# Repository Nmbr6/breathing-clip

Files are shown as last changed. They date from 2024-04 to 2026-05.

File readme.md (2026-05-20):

# Real-time Wearable Respiratory Monitoring System

This project develops a proof-of-concept real-time respiratory monitoring system designed to be non-intrusive, capable of capturing recognizable breathing signals, and transmitting the data over UDP. It is aimed at enabling respiratory based interactions, ensuring simple mounting and adaptability to different positions.

## Referencing

If you use the code or 3D print files included here for your research, please kindly cite the relevant papers in your publications. This support is critical for the continued development and maintenance of the software, as well as recognition of the effort by the authors. Relevant publications include:
* BreathClip: A Wearable Respiration Sensor for Interaction Design \[[link](https://doi.org/10.18420/muc2025-mci-demo-306)]
* Enriched Embodiment Environments for Healthcare Spaces: Exploration through the Design of a Cancer Treatment Facility \[[link](https://doi.org/10.1145/3706599.3719733)]
  
### Other breathing projects:
* Breathing based immersive interactions for enhanced agency and body awareness: a claustrophobia motivated study \[[link](https://dl.acm.org/doi/full/10.1145/3544549.3585897)]
* Enhancing interoceptive sensibility through exteroceptive–interoceptive sensory substitution \[[link](https://doi.org/10.1038/s41598-024-63231-4)]

## Platform

- **Device**: [M5 StickC Plus2](https://docs.m5stack.com/en/core/M5StickC%20PLUS2), built on the ESP32-PICO-V3-02 SoC.
- **IMU**: MPU6886 6-axis IMU for motion tracking.
- **Power**: Equipped with a 200mAh battery.
- **WiFi**: Onboard 2.4GHz antenna utilizing the ESP32 WiFi stack for data transmission.

## Wi-Fi Transmitter Details

- **Wi-Fi Protocol**: 2.4GHz (802.11b/g/n).
- **UDP Port**: 1234 for data streaming.
- **Output Data Rate**: ~500Hz, corresponding to every 2ms.
- **IP Address**: Assigned dynamically.
- **Device Identifier**: Incorporates a "patient_id" as an unsigned 4-digit integer.
- **Packet Type**: 20-byte string format "patient_id,elapsedTime,ac_sig", where:
  - `patient_id` is an unsigned 4-digit integer.
  - `elapsedTime` is an unsigned 32-bit integer, indicating time in milliseconds since power-on, with a maximum stored value representing 49.7 days.
  - `ac_sig` is a signed 16-bit integer showing the accelerometer signal in G-force (units of 0.1mG).

## User Input/Output

- **Front Button**: Toggles the device's LED on or off.
- **Side Button**: Pauses or resumes the UDP stream, effectively toggling the stream state.
- **PWR Button**: Powers the device on (long press ~2 seconds) or off (long press ~6 seconds).

## First-time Setup

**Arduino Libraries**
- M5StickCPlus2 (1.0.1)
- M5Family (0.1.3)
- M5Stack (0.4.6)
- M5Unified (0.1.14)

Accept all dependencies when installing or updating.

**Arduino Board Manager**
- M5Stack (v2.0.7)

**Drivers**
- Install CH9102 UART driver [here](https://docs.m5stack.com/en/core/M5StickC%20PLUS2) ('Driver Installation').
Choose appropriate installer for Windows or MacOS.

**Header Files**
- In your Arduino libraries folder, navigate to <...\Arduino\libraries\M5Unified\src\utility\imu>
Open MPU6886_Class.cpp, then edit Line 61 to match this: setAccelFsr(Ascale::AFS_2G);
This adjusts the full-scale range of IMU data to its highest resolution (+/- 2G)
- To run the code effectively, modify the IMU header file within the M5StickC library to set the resolution to its maximum by editing the `MPU6886.h` file: change line 66 to `Ascale Acscale = AFS_2G;`.

## Before Sketch Upload

- Edit Patient ID: set unique alphanumeric ID per unit (Line 24)
- Edit WiFi credentials (Lines 27-28)

## Mounting

We suggest two methods for mounting - magnetic tape, or a 3D printed clip which can be found in the Git.
### Magnetic tape
 We used Magnetic tape with adhesive backing, with one segment attached to the device, and one simply placed inside the garment. 
 
### 3D printed clip
The STL for printing the clip can be found [here](https://github.com/Nmbr6/breathing-clip/blob/main/Sensor%20Clip.STL) in the GIT. We suggest printing it vertically, oriented so that the clip opening is facing up.

<p align="center">
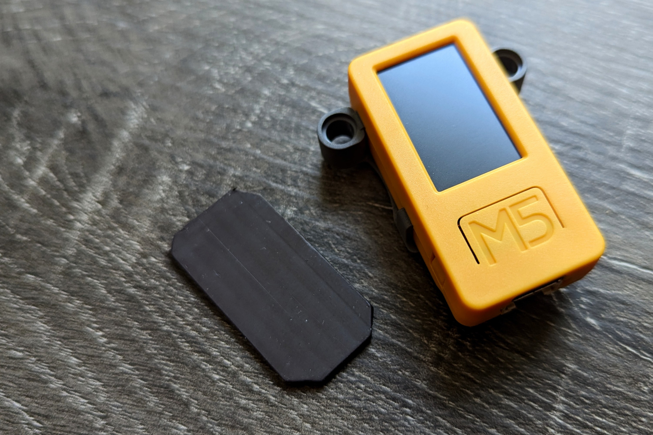
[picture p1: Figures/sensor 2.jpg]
    
</p>

## Placement

For optimal signal capture, the device should be placed over clothing on the clavicle, approximately midway between the sternoclavicular and acromioclavicular joints. The M5 StickC Plus2 should be perpendicular to the clavicle, ensuring accurate signal detection.

<p align="center">
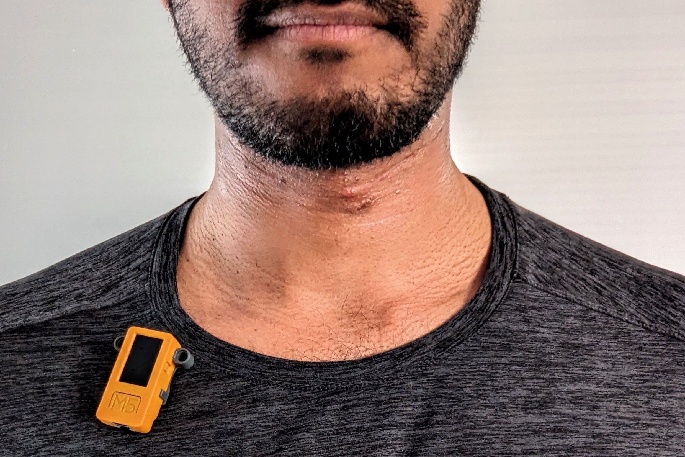
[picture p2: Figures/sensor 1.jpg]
  
</p>

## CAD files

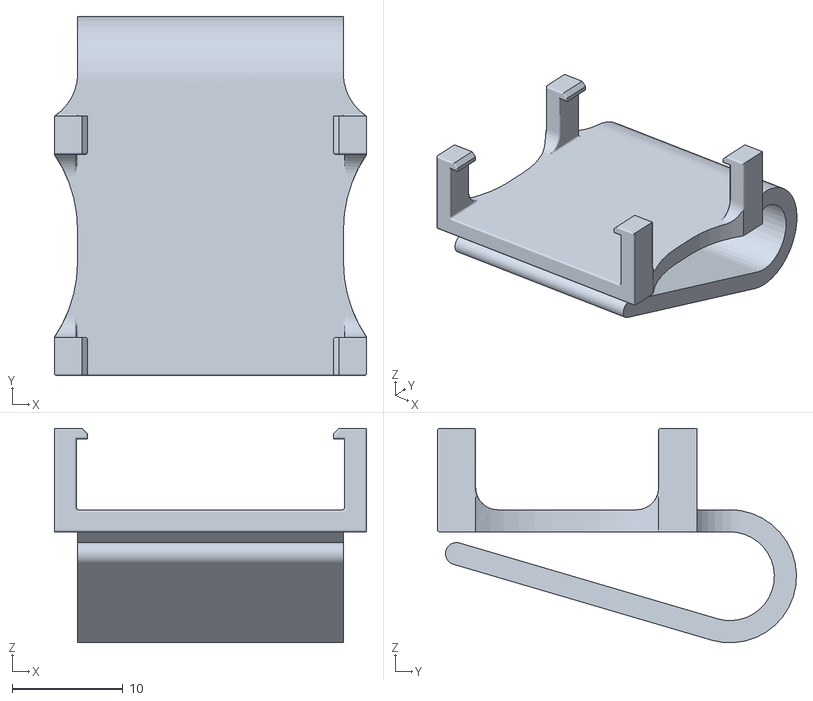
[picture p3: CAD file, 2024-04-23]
Sensor Clip.STL
28.2 x 32.4 x 19.3

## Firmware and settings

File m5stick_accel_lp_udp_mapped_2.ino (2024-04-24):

/*  Proof-of-concept code for Breathing Clip sensor
 *  Shreyas Renganathan, 4/14/2024
 *  This sketch is written for the M5StickCPlus2.
 *  This sketch continuously reads the onboard IMU (MPU6886), filters the data, and streams it over a WiFi network via UDP broadcast
 *  Output data rate is ~500Hz in empirical testing, but will vary based on network speed/bandwidth.
 *  Signal processing algorithm maps the breathing signal output b(t) to -1000<b(t)<1000. The intent is that this can be divided by 1000.0 on the receiver side to obtain a float value -1.0<B(t)<1.0.
 *  This algorithm works by variously filtering the signal to remove noise, then clipping it to a preset range that is known to be narrower than the observed range.
 *  This clipped sinewave is then lowpass filtered again to reconstruct a sinusoidal signal. The reconstructed signal is therefore effectively mapped to the preset range.
 *  NOTE: Follow all setup instructions in Readme.md first
 */
#include "M5StickCPlus2.h"
#include "WiFi.h"
#include "AsyncUDP.h"

/* INITIALIZATIONS */
const int LED_PIN=19;
const bool OFF=HIGH;
const bool ON=LOW;
bool STREAM_EN = false;
bool LED_STATE = ON;
int streamPrint = false;

/* Enter patient ID# here */
const int patient_id = 2308;

/* Set WiFi credentials here */
const char* ssid = "SJMnetwork2.4";
const char* password = "Muddy0607";

/* Enter device IP address and port here*/
//IP address doesn't really matter, it's just a placeholder to start the connection
//Gets replaced by a dynamic IP after connection
const int ipAddress[4] = {192,168,1,100}; 
//Port matters, ensure this matches the port set on your receiver
const int port = 1234;

float accX, accY, accZ;
//float gyrX, gyrY, gyrZ; //for angular rate measurements

float filt_sig = 0.0;
float dc_sig = 0.0;
float ac_sig = 0.0;
float upper_limit=0.2;
float lower_limit=-0.2;
float ac_sig_reconst=0.0;
int ac_sig_reconst_1000=0;

unsigned long elapsedTime=millis();
unsigned long startTime=millis();

// Class to define lowpass filter.
// Order can be 1 (first order) or 2 (second order) */
template <int order>
class LowPass{
  private:
    float a[order];
    float b[order+1];
    float omega0;
    float dt;
    bool adapt;
    float tn1 = 0;
    float x[order+1]; // Raw values
    float y[order+1]; // Filtered values

  public:  
    LowPass(float f0, float fs, bool adaptive){
      // f0: cutoff frequency (Hz)
      // fs: sample frequency (Hz)
      // adaptive: if 1, sample frequency will auto-adjust based on time history

      // Convert cutoff frequency (Hz) to angular frequency (rad/s)
      // i.e. w0=2*pi*f0
      omega0 = 6.28318530718*f0;
      
      //Calculate timestep from sampling frequency
      dt = 1.0/fs;
      
      adapt = adaptive;
      tn1 = -dt;
      for(int k = 0; k < order+1; k++){
        x[k] = 0;
        y[k] = 0;        
      }
      // Set filter coefficients
      setCoef();
    }
    
    // Set filter coefficients
    void setCoef(){
      if(adapt){
        float t = micros()/1.0e6;
        dt = t - tn1;
        tn1 = t;
      }
      
      float alpha = omega0*dt;
      if(order==1){
        a[0] = -(alpha - 2.0)/(alpha+2.0);
        b[0] = alpha/(alpha+2.0);
        b[1] = alpha/(alpha+2.0);        
      }
      if(order==2){
        float alphaSq = alpha*alpha;
        float beta[] = {1, sqrt(2), 1};
        float D = alphaSq*beta[0] + 2*alpha*beta[1] + 4*beta[2];
        b[0] = alphaSq/D;
        b[1] = 2*b[0];
        b[2] = b[0];
        a[0] = -(2*alphaSq*beta[0] - 8*beta[2])/D;
        a[1] = -(beta[0]*alphaSq - 2*beta[1]*alpha + 4*beta[2])/D;      
      }
    }

    // For given raw value x, calculate and output filtered value y
    float filt(float xn){
      if(adapt){
        //if adaptive=1, update filter coefficients each time this function is called
        setCoef();      
      }
      y[0] = 0;
      x[0] = xn;
      
      // Calculate filtered values
      for(int k = 0; k < order; k++){
        y[0] += a[k]*y[k+1] + b[k]*x[k];
      }
      y[0] += b[order]*x[order];

      // Save history of raw and filtered values
      for(int k = order; k > 0; k--){
        y[k] = y[k-1];
        x[k] = x[k-1];
      }
  
      // Output filtered value    
      return y[0];
    }
};

/*Instantiate lowpass filters
 * f0: cutoff frequency (Hz)
 * fs: sample frequency (Hz)
 * adaptive: boolean flag, if set to 1, the code will automatically set the sample frequency based on the time history.
 */
// Lowpass filter on raw data. Cutoff freq of 0.9Hz comes from Hughes et al (2020)
// https://www.ncbi.nlm.nih.gov/pmc/articles/PMC7363979/
LowPass<2> raw_lp(0.9,1000,true);

// Lowpass filter to extract DC offset i.e low-frequency noise like motion artifacts
// Subtracting this DC offset from the main lowpass filter above effectively bandpass-filters the signal
// Cutoff freq of 0.15Hz was set observationally- trying to balance rapid tracking of the DC offset with capturing breath signals below the lower frequency bound of normal (12bpm=0.2Hz)
LowPass<2> dc_lp(0.15,1000,true);

// Lowpass filter to reconstruct sine wave from clipped breathing signal
LowPass<2> rc_lp(0.7,1000,true);

//Instantiate UDP
AsyncUDP udp;

/* SETUP */      
void setup() {
  //Set GPIO4 to HIGH upon bootup as recommenDed by M5StickCPlus2 documentation
  pinMode(4,OUTPUT);
  digitalWrite(4,HIGH);
  //Turn off display backlight
  analogWrite(27,0);
  //Write ON state (active LOW) to LED
  pinMode(LED_PIN,OUTPUT);
  digitalWrite(LED_PIN,ON);
  //Initialize M5StickCPlus for IMU reads and button reads
  auto cfg = M5.config();
  StickCP2.begin(cfg);
  //Disable LCD screen & backlight
  //M5.Lcd.writecommand(ILI9341_DISPOFF);
  M5.Lcd.setBrightness(0);
  /*
  //Disable LCD screen
  M5.begin(0,1,1);
  //Turn off LCD backlight
  M5.Axp.SetLDO2(false);
  //Initialize IMU
  M5.IMU.Init();
  */
  //Initialize Serial communication (necessary only for debug)
  Serial.begin(115200);
  //Connect to an existing WiFI network
  WiFi.mode(WIFI_STA);
  WiFi.begin(ssid, password);
  if (WiFi.waitForConnectResult() != WL_CONNECTED) {
      Serial.println("WiFi Failed");
      while(1) {
          delay(1000);
      }
  }
  if(udp.connect(IPAddress(ipAddress[0],ipAddress[1],ipAddress[2],ipAddress[3]), port)) {
      Serial.println("UDP connected");
  }
  //Need to have this so M5Stack doesn't complain about LED not being initialized
  ledcSetup(0,0,12);
}

/* LOOP */
void loop() {
  //Check for new button presses using M5Stack
  StickCP2.update();
  //If main button was pressed, toggle stream enable and reset timer;
  if(StickCP2.BtnA.wasPressed()){
    STREAM_EN=!STREAM_EN;
    startTime=millis();
  }
  //Update elapsed time
  elapsedTime=millis()-startTime;

  //Get raw accelerometer data
  auto imu_update = StickCP2.Imu.update();
  auto data = StickCP2.Imu.getImuData();
  accZ=data.accel.z;
  //Lowpass-filter the raw data
  filt_sig = raw_lp.filt(accZ)*100.0;
  //Lowpass-filter at a lower freq to extract DC offset
  dc_sig = dc_lp.filt(accZ)*100.0;
  //Subtract DC offset from data to get signal centered at zero
  ac_sig = filt_sig - dc_sig;

  //Clip signal on both top and bottom
  if (ac_sig>upper_limit) ac_sig=upper_limit;
  if (ac_sig<lower_limit) ac_sig=lower_limit;

  //Reconstruct sinewave by lowpass-filtering the clipped signal
  ac_sig_reconst=rc_lp.filt(ac_sig)*1000;
  
  //Clip again to remove filter artifacts
  if (ac_sig_reconst>upper_limit*1000.0) ac_sig_reconst = upper_limit*1000.0;
  if (ac_sig_reconst<lower_limit*1000.0) ac_sig_reconst = lower_limit*1000.0;

  //Rescale reconstructed signal to -1000<signal<1000
  //Scaling factor is 1000/(upper_limit*10000)=1/upper_limit
  ac_sig_reconst_1000=ac_sig_reconst*(1.0/upper_limit);

  //Send broadcast on port 1234
  char buf[20];
  if(STREAM_EN){
    LED_STATE=ON;
    //Construct buffer to send over UDP
    sprintf(buf,"%d,%ul,%d",patient_id,elapsedTime,ac_sig_reconst_1000);
    udp.broadcastTo(buf, 1234);
    if (streamPrint){
      Serial.print(ac_sig_reconst_1000);
      Serial.println();
    }
  }
  else LED_STATE=OFF;
  digitalWrite(LED_PIN,LED_STATE);
  delay(2);
}

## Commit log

2024-04-14 First commit
    Breathing clip code retooled for M5StickCPlus2. Includes README, and UART driver for Serial communication
2024-04-14 new folder for Drivers
2024-04-23 Rename sensor 1.jpg to Figures/sensor 1.jpg
2024-04-23 Rename sensor 2.jpg to Figures/sensor 2.jpg
2024-04-23 Add files via upload
    3D model for sensor clip
    [Sensor Clip.STL]
2024-04-24 Updated with current observed output data rate
2024-04-24 Update readme.md with current Output Data Rate
